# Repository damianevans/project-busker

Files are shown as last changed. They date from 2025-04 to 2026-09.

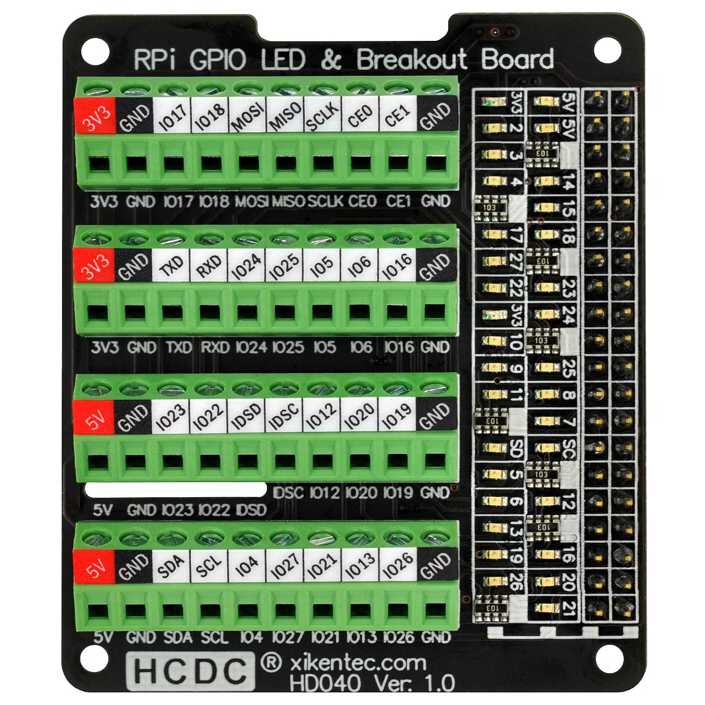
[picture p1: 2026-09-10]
hardware/rpi-gpio-breakout-board.png

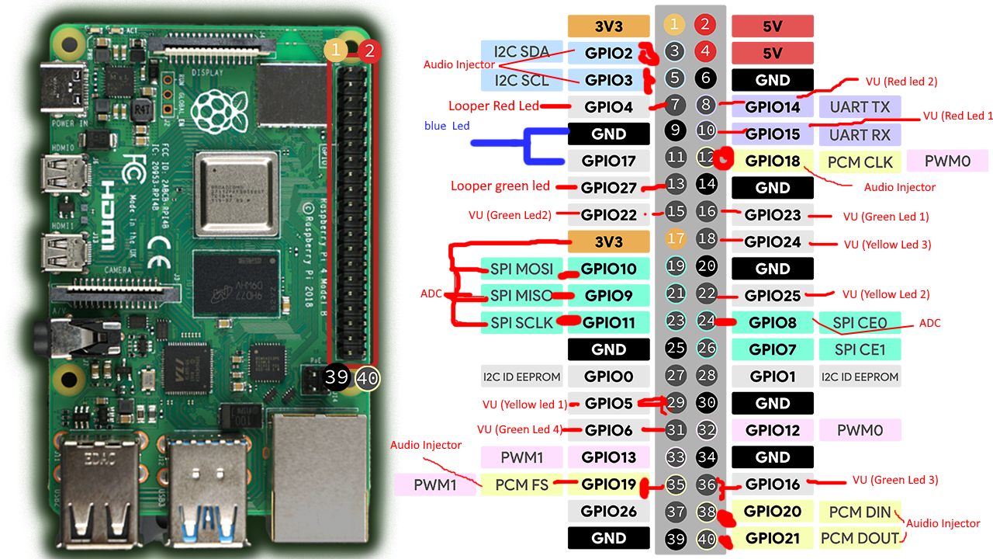
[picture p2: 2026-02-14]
hardware/pi-pins-in-use.png

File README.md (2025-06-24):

# Project Busker

I promised I would build my daughter a busking amp for her Birthday. That was 18 months ago 😫
This project is based on the excellent hackaday article from David Silverman (details below).
The final plan is for a self-contained busking amp with the following features:
- 2 XLR microphone inputs, each with it's own pre-amp and reverb module.
- An electric guitar amp with effects, built using a raspberry pi 4 with an AudioInjector hat
- A hardware mixer
- a power amp

# David Silverman's guitarpedal links
Guitar Pedal for Raspberry pi using Python and PYO library 

Technical documentation being worked on here:

https://docs.google.com/presentation/d/1GgiD2UTEGcz-SC2rGDjdIljaK2Yn0Rs03TDFOu3duUw/edit?usp=sharing

Video demo here:

https://www.youtube.com/watch?v=wl24fLW1fQE

In depth code walkthrough here:

https://www.youtube.com/watch?v=LpFfZ5o4mEs

Looper video here:

https://youtu.be/jMI3nN0OYLE

Hackaday project here:

https://hackaday.io/project/186218-raspberry-pi-guitar-amplifier

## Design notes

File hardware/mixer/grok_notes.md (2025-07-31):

## Notes on the Schematic File
### Components:
- NE5532: Uses the NE5532 symbol from the Amplifier_Operational library in KiCad.
- Capacitors: Generic C symbol from the Device library, set to 10µF (electrolytic, ensure polarity is correct in PCB layout).
- Resistors: Generic R symbol from the Device library, with values specified (10kΩ, 1MΩ, 100Ω, 47Ω, 20kΩ).
- Potentiometers: Uses CPOT from the Device library for 100kΩ faders.
- Connectors:J1: 1/4" TRS jack, approximated as Conn_01x03 (tip, sleeve, ring; sleeve and ring can be grounded for mono).
- J2: 3.5mm TRS jack with switch, approximated as Conn_01x04 (tip, ring, sleeve, switch pin). You may need a custom symbol for a switching 3.5mm jack (see below).

Power: Uses +12V, -12V, and GND symbols from the power library.

### Limitations:
- 3.5mm Jack with Switch: KiCad’s standard library may not have a 3.5mm TRS jack with a switching pin. The schematic uses a Conn_01x04 placeholder. You may need to create a custom symbol in KiCad’s Symbol Editor with pins for tip, ring, sleeve, and a normally closed switch pin that opens when a plug is inserted. Alternatively, use a generic connector and annotate the switching behavior.
- Headphone Output Simplification: The schematic assumes a mono output for simplicity (summing stage feeds both headphone channels). For stereo, duplicate the headphone output stage (U4B, R18, C11) and connect to J2’s ring pin.
- Input Connectors: Channels 1–3 use labels (IN1, IN2, IN3) instead of jacks, as they’re internal connections.

### Connections:
Wires connect components as described in the previous circuit description.
The summing stage (U3A) combines all four channels via 10kΩ resistors (R10–R13).
The output stage splits to line out (via R16) and headphone out (via U4A, R17, C10).
Power connections (±12V, GND) are made to all NE5532 op-amps, with decoupling capacitors (C11, C12: 100nF) near U1/U2.

Coordinates:Components are placed on an A4 sheet with approximate X, Y coordinates (in mils) to avoid overlap.
Channels 1–4 are vertically stacked (Y=2800, 4300, 5800, 7300) for clarity.
Summing stage is at X=5000, output stage at X=7000–8000.

Custom Symbol for 3.5mm Jack (if Needed)If KiCad lacks a 3.5mm TRS jack with a switch, create one:In Symbol Editor: Create a symbol named TRS_3.5mm_Switch.
Add pins:Pin 1: Tip (audio left, input/output).
Pin 2: Ring (audio right, input/output).
Pin 3: Sleeve (ground).
Pin 4: Switch NC (normally closed, connects to line out when unplugged).

Save and use this symbol for J2, connecting Pin 4 to R16 (line out) and Pin 1 to R17 (headphone out).

## Additional Notes

### Mono vs. Stereo: 
The schematic is designed for mono output for simplicity. For stereo, duplicate the headphone output stage (add U4B, R18, C11) and connect to J2’s ring pin.
Power Supply: Ensure ±12V rails are connected to all NE5532 power pins (V+ = pin 8, V- = pin 4). Add more decoupling capacitors (100nF) near U3 and U4 if needed.
Testing: After loading the schematic, simulate in a tool like LTspice (export netlist) to verify gain, frequency response, and headphone drive capability.
Footprint Assignment: Choose appropriate footprints in KiCad’s PCB Editor (e.g., DIP-8_W7.62mm for NE5532, PinHeader_1x3 for J1, PhoneJack_3.5mm for J2).

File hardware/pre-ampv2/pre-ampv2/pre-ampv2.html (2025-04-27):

# C:\Users\admin\Google Drive\KiCad\Busker-amp\guitar-pre-amp\pre-ampv2\pre-ampv2\pre-ampv2.sch

12/03/2025 23:24:18

Eeschema (5.1.10)-1

Component Count:15

Ref | Qnty | Value | Part | Datasheet | Description | Vendor
C1, C3, C5 | 3 | 10u | Device:CP | ~ | Polarized capacitor
C2 | 1 | 0.1u | Device:C | ~ | Unpolarized capacitor
C4 | 1 | 560p | Device:C | ~ | Unpolarized capacitor
J1 | 1 | Conn_01x02_Male | Connector:Conn_01x02_Male | ~ | Generic connector, single row, 01x02, script generated (kicad-library-utils/schlib/autogen/connector/)
J2 | 1 | Out | Connector:Conn_01x02_Male | ~ | Generic connector, single row, 01x02, script generated (kicad-library-utils/schlib/autogen/connector/)
R1, R3 | 2 | 100K | Device:R | ~ | Resistor
R2 | 1 | 1M | Device:R | ~ | Resistor
R4 | 1 | 1K | Device:R | ~ | Resistor
R5 | 1 | 10K | Device:R | ~ | Resistor
R6 | 1 | 220 | Device:R | ~ | Resistor
RV1 | 1 | 100K | Device:R_POT | ~ | Potentiometer
U1 | 1 | NE5532 | Amplifier_Operational:NE5532 | http://www.ti.com/lit/ds/symlink/ne5532.pdf | Dual Low-Noise Operational Amplifiers, DIP-8/SOIC-8

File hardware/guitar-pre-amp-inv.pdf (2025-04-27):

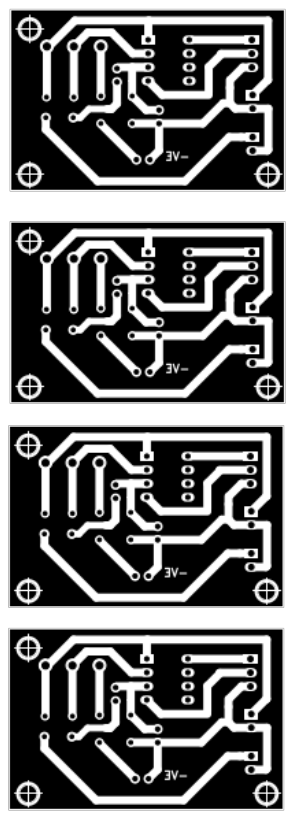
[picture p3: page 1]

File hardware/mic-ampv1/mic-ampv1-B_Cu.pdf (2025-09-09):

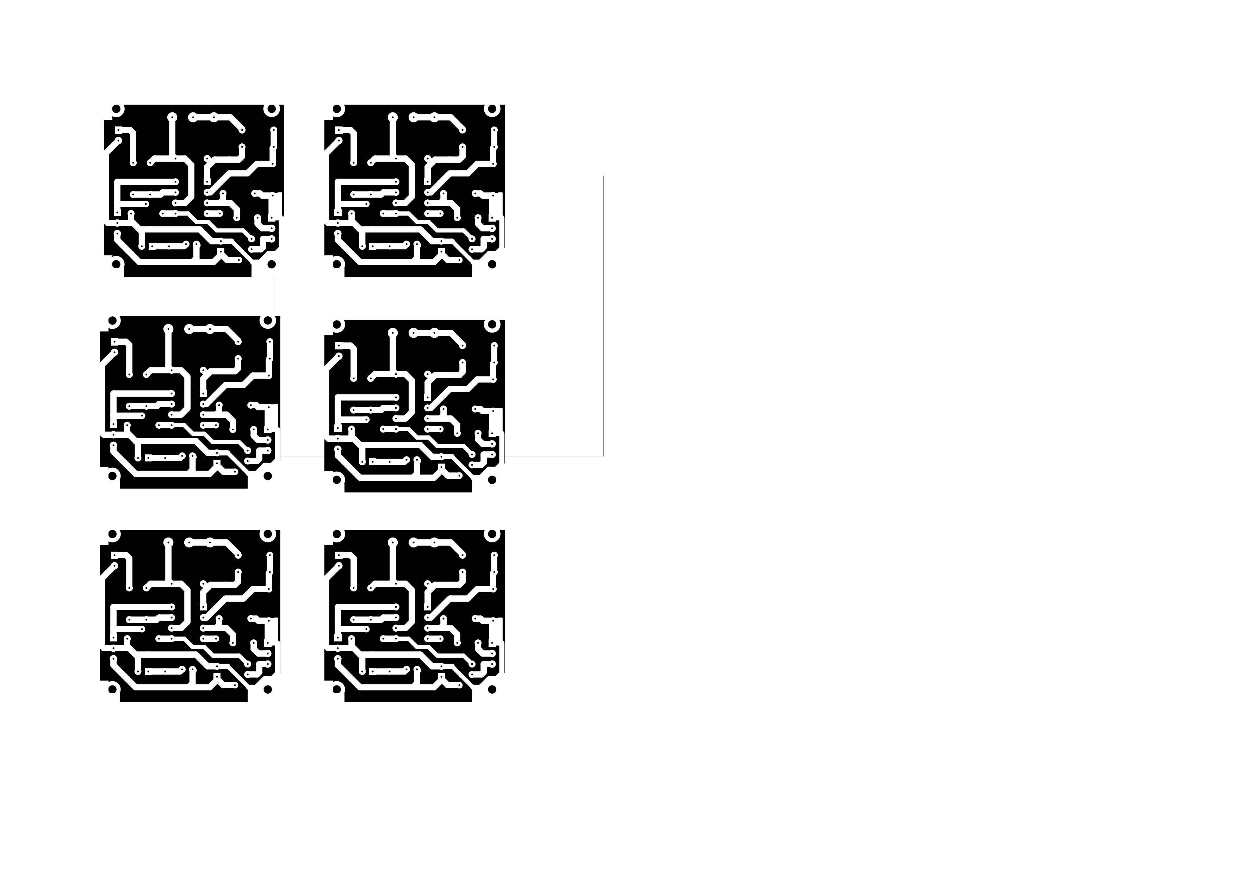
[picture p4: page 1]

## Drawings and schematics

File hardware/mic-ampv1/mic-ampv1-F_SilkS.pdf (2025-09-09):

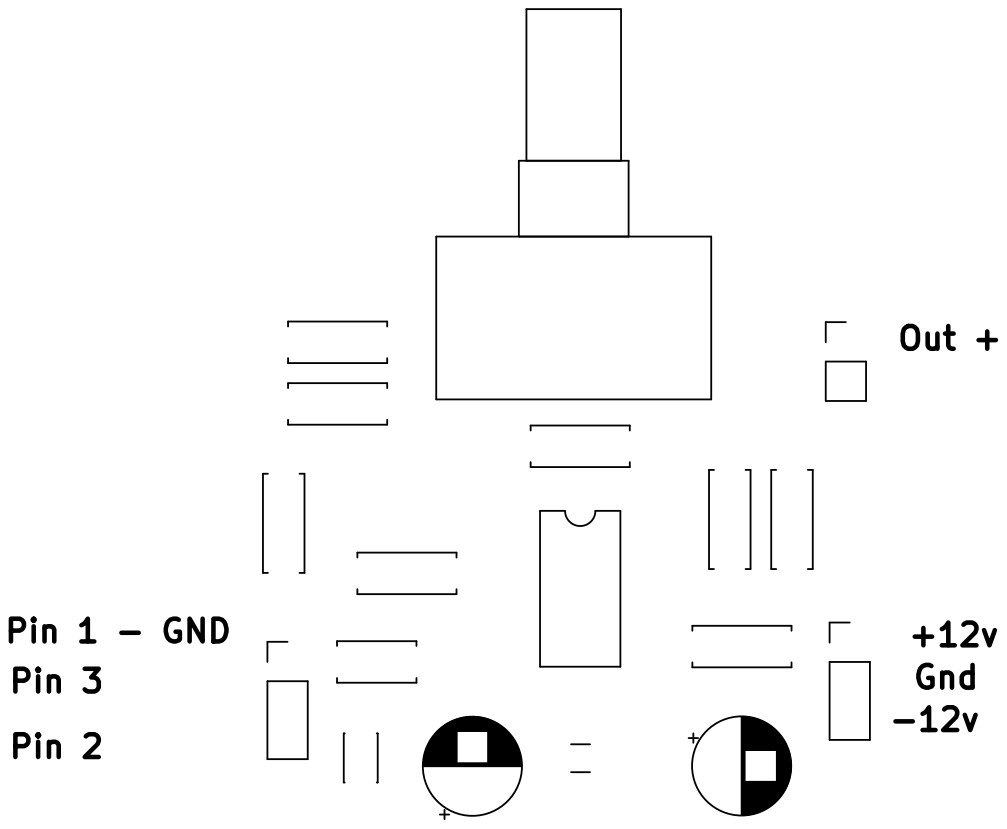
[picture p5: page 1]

+12v Out + Pin 2 Pin 3 Pin 1 - GND

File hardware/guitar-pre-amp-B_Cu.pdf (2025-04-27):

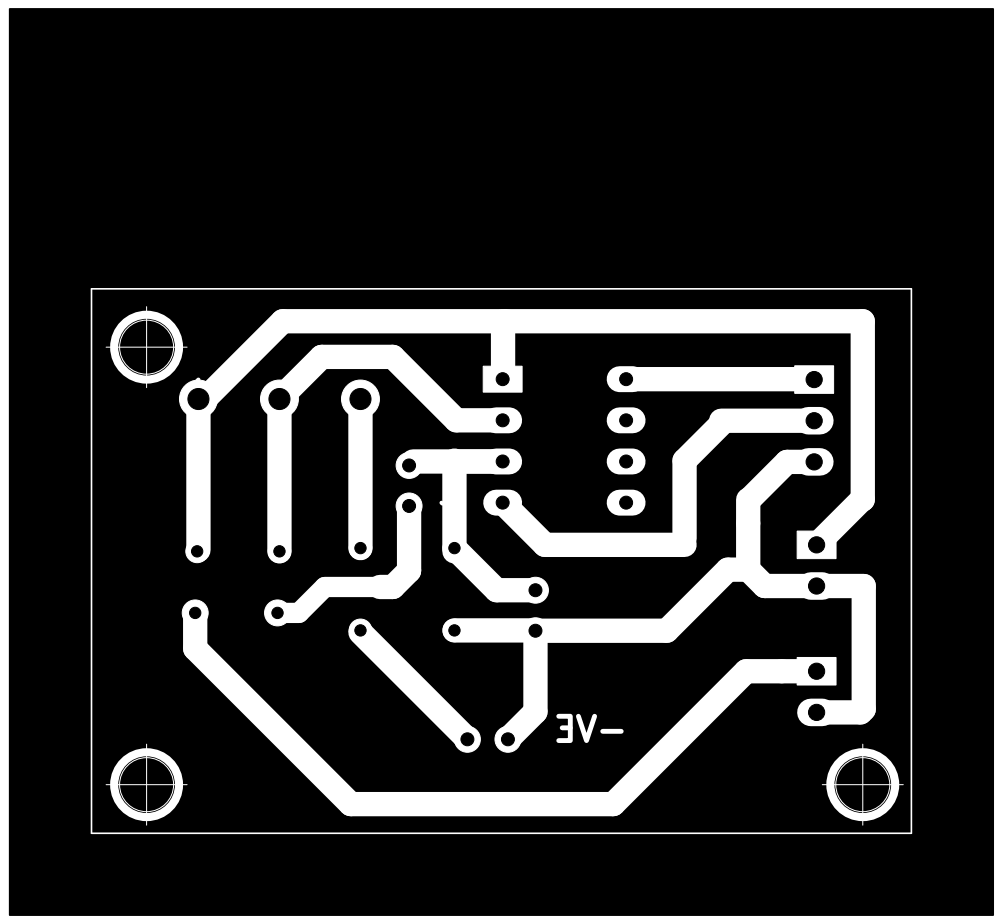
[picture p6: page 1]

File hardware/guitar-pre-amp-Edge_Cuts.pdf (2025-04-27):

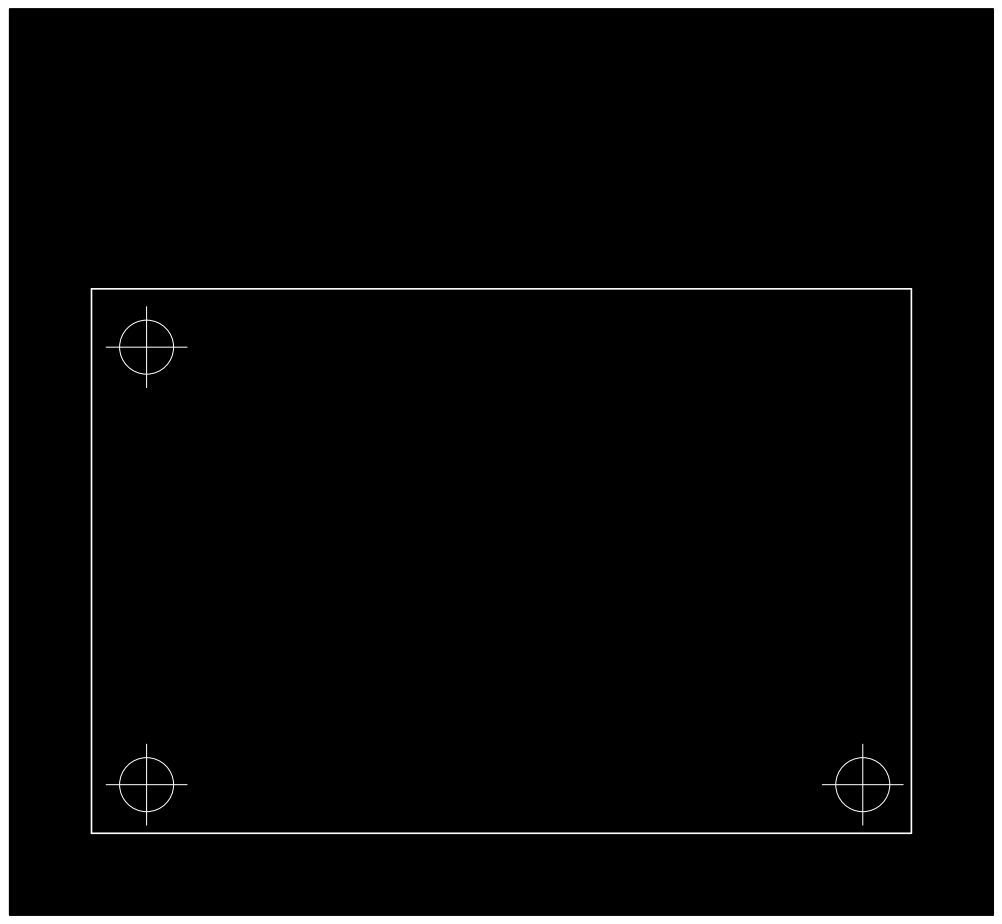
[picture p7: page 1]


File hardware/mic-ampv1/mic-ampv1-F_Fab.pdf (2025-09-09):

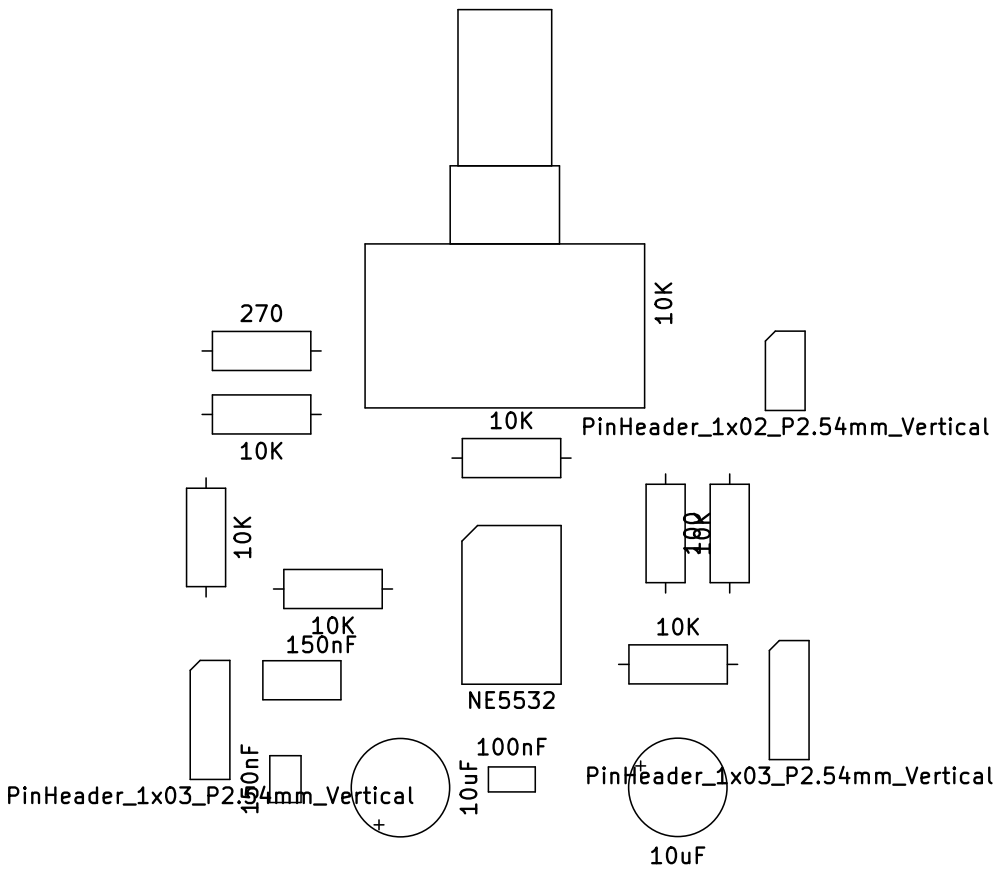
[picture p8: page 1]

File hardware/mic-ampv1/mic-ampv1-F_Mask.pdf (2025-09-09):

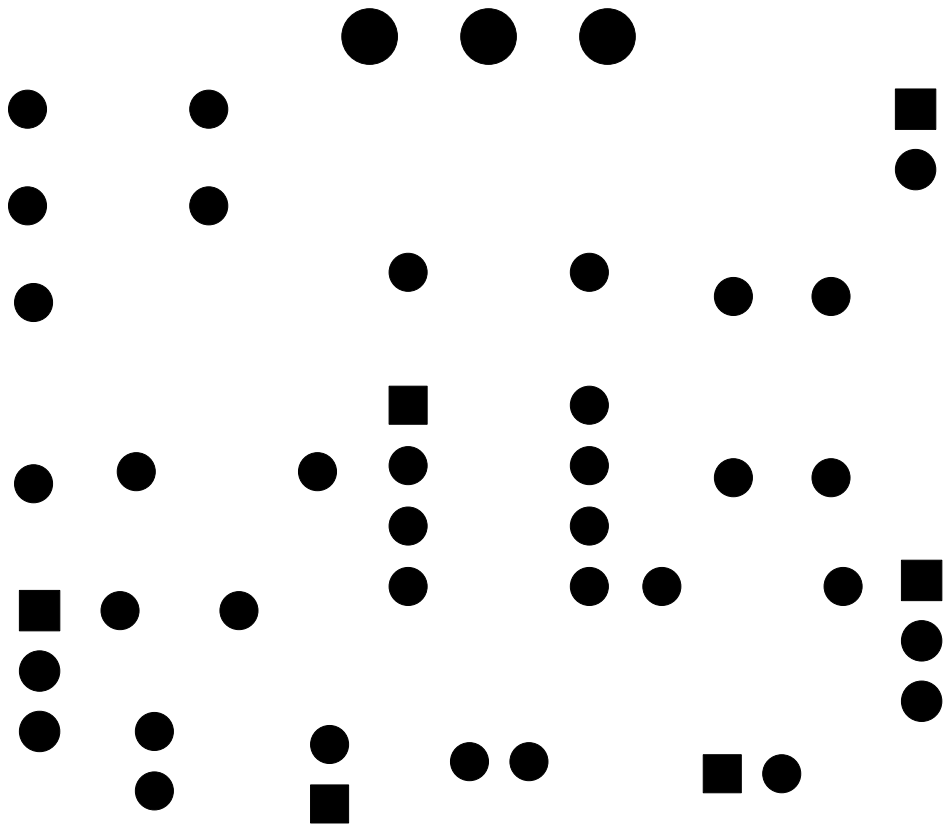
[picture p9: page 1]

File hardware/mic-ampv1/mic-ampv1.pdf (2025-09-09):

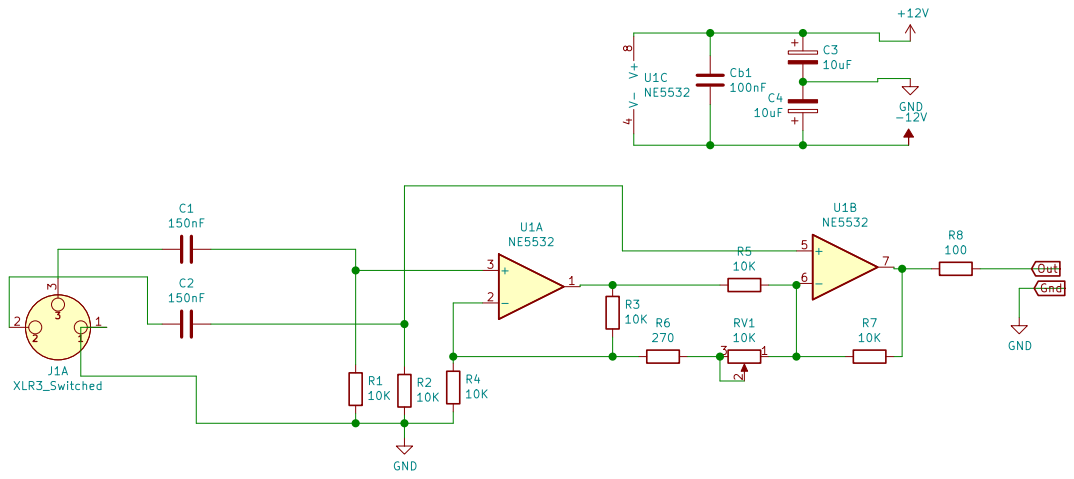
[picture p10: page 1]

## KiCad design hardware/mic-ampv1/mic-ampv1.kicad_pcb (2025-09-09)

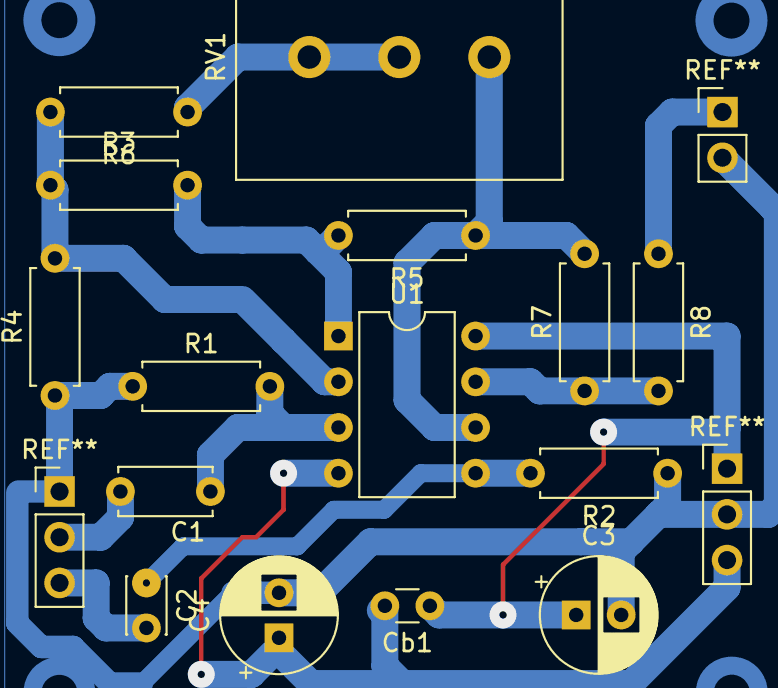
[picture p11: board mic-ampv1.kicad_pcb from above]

Board: 2 copper layers, 15 parts (0 on the bottom side), 10 nets.

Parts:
C1: 150nF; C_Disc_D5.0mm_W2.5mm_P5.00mm
C2: 150nF; C_Disc_D3.0mm_W2.0mm_P2.50mm
C3, C4: 10uF; CP_Radial_D6.3mm_P2.50mm
Cb1: 100nF; C_Disc_D3.0mm_W1.6mm_P2.50mm
R1, R2, R3, R4, R5, R7: 10K; R_Axial_DIN0207_L6.3mm_D2.5mm_P7.62mm_Horizontal
R6: 270; R_Axial_DIN0207_L6.3mm_D2.5mm_P7.62mm_Horizontal
R8: 100; R_Axial_DIN0207_L6.3mm_D2.5mm_P7.62mm_Horizontal
RV1: 10K; Potentiometer_Alps_RK163_Single_Horizontal
U1: NE5532; DIP-8_W7.62mm

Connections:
+12V: C3.1, Cb1.1, U1.8
-12V: C4.1, Cb1.2, U1.4
Gnd: C3.2, C4.2, R1.1, R2.1, R4.1
unnamed: C1.1, R1.2, U1.3
unnamed: C2.1, R2.2, U1.5
unnamed: R3.1, R4.2, R6.2, U1.2
unnamed: R3.2, R5.2, U1.1
unnamed: R5.1, R7.2, RV1.1, U1.6
unnamed: R6.1, RV1.2, RV1.3
unnamed: R7.1, R8.2, U1.7

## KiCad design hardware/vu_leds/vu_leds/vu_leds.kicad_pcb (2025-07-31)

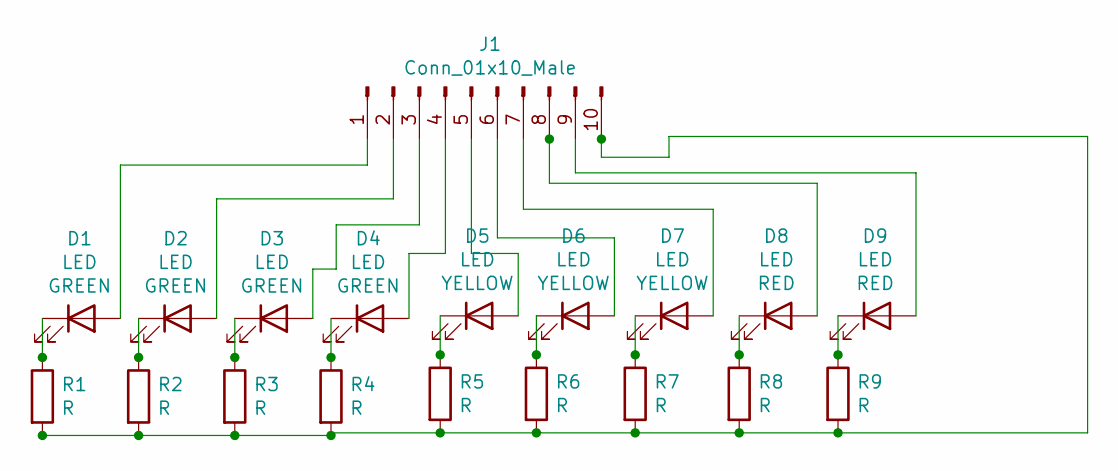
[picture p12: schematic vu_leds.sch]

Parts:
D1, D2, D3, D4, D5, D6, D7, D8, D9: LED; LED_Rectangular_W5.0mm_H2.0mm
J1: Conn_01x10_Male; PinHeader_1x10_P2.54mm_Horizontal
R1, R2, R3, R4, R5, R6, R7, R8, R9: R; R_Axial_DIN0207_L6.3mm_D2.5mm_P7.62mm_Horizontal

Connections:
unnamed: D1.1 (K), R1.1
unnamed: D1.2 (A), J1.1
unnamed: D2.1 (K), R2.1
unnamed: D2.2 (A), J1.2
unnamed: D3.1 (K), R3.1
unnamed: D3.2 (A), J1.3
unnamed: D4.1 (K), R4.1
unnamed: D4.2 (A), J1.4
unnamed: D5.1 (K), R5.1
unnamed: D5.2 (A), J1.5
unnamed: D6.1 (K), R6.1
unnamed: D6.2 (A), J1.6
unnamed: D7.1 (K), R7.1
unnamed: D7.2 (A), J1.7
unnamed: D8.1 (K), R8.1
unnamed: D8.2 (A), J1.8
unnamed: D9.1 (K), R9.1
unnamed: D9.2 (A), J1.9
unnamed: J1.10, R1.2, R2.2, R3.2, R4.2, R5.2, R6.2, R7.2, R8.2, R9.2

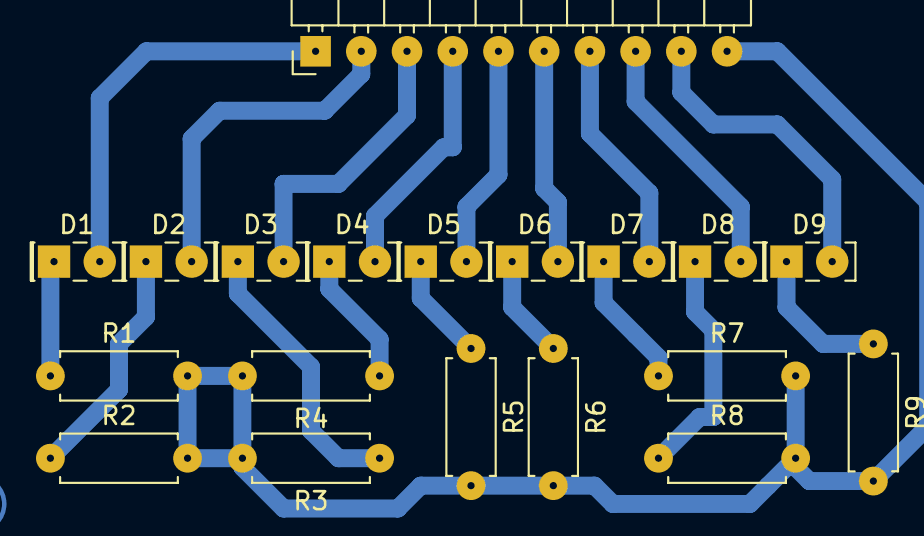
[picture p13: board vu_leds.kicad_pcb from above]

Board: 2 copper layers, 19 parts (0 on the bottom side), 19 nets.

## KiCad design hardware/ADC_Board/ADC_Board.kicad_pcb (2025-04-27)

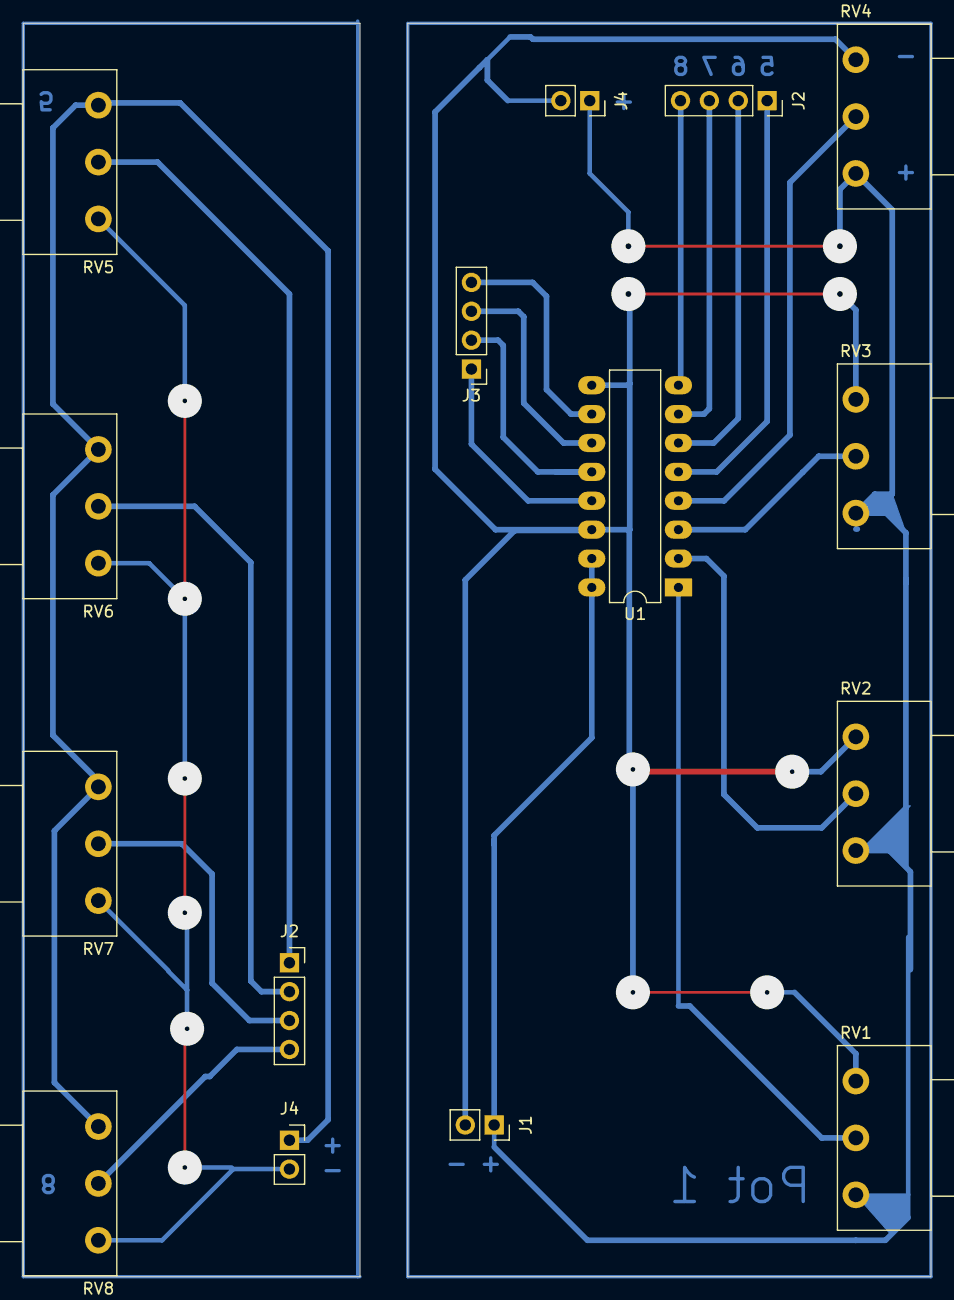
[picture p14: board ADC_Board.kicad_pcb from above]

Board: 2 copper layers, 79.8 x 110.2 mm, 15 parts (0 on the bottom side), 12 nets.

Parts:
J1, J4, J4#2: Conn_01x02_Female; PinSocket_1x02_P2.54mm_Vertical
J2, J2#2: Conn_01x04_Female; PinSocket_1x04_P2.54mm_Vertical
J3: Conn_01x04_Female; PinHeader_1x04_P2.54mm_Vertical
RV1, RV2, RV3, RV4, RV5, RV6, RV7, RV8: R_POT; Potentiometer_Piher_PC-16_Single_Horizontal
U1: MCP3008; DIP-16_W7.62mm_LongPads

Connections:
unnamed: J2#2.1, U1.5
unnamed: J2#2.2, U1.6
unnamed: J2#2.3, U1.7
unnamed: J2#2.4, U1.8
unnamed: J3.1, U1.13
unnamed: J3.2, U1.12
unnamed: J3.3, U1.11
unnamed: J3.4, U1.10
unnamed: RV1.2, U1.1
unnamed: RV2.2, U1.2
unnamed: RV3.2, U1.3
unnamed: RV4.2, U1.4

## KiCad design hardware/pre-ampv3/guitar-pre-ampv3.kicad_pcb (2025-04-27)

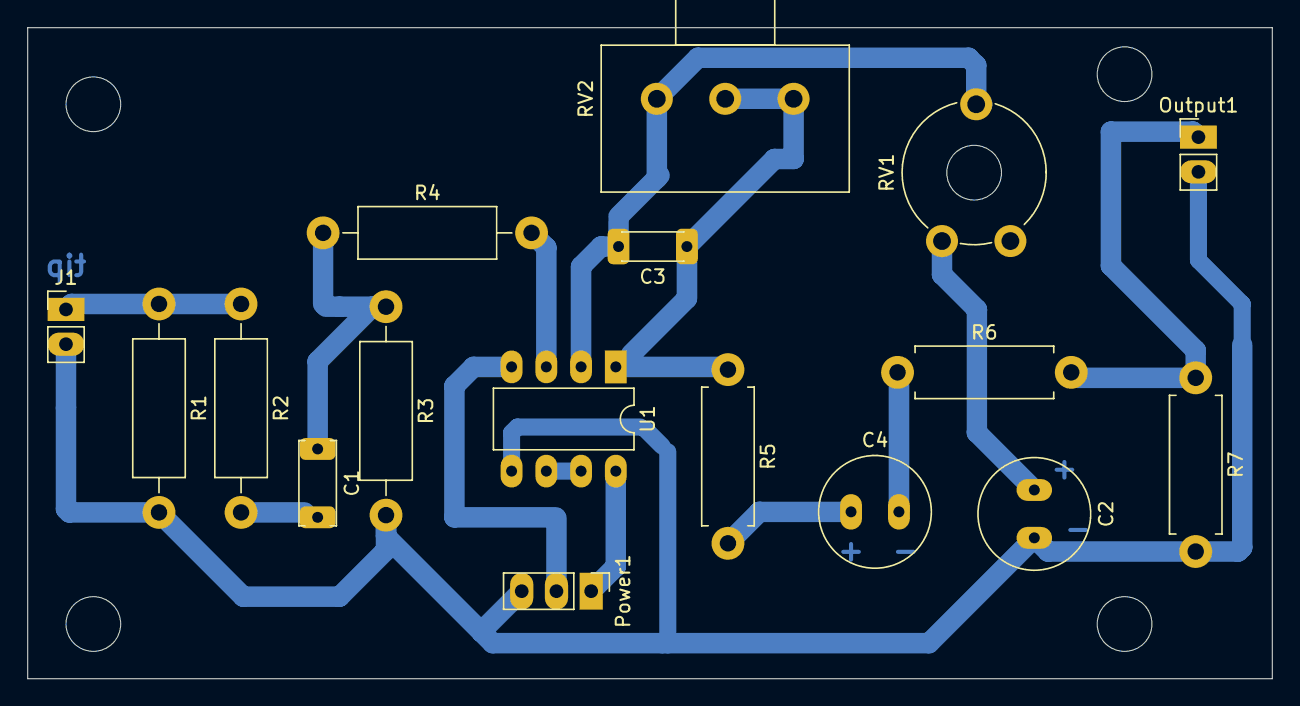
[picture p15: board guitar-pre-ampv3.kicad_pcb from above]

Board: 2 copper layers, 91.0 x 47.6 mm, 17 parts (0 on the bottom side), 12 nets.

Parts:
C1: 100n; C_Disc_D6.0mm_W2.5mm_P5.00mm
C2, C4: 10uF; C_Radial_D8.0mm_H11.5mm_P3.50mm
C3: 100p; C_Disc_D4.3mm_W1.9mm_P5.00mm
J1: Input; PinHeader_1x02_P2.54mm_Vertical
Output1: Conn_01x02_Male; PinHeader_1x02_P2.54mm_Vertical
Power1: pwr; PinHeader_1x03_P2.54mm_Vertical
R1: 470k; R_Axial_DIN0411_L9.9mm_D3.6mm_P15.24mm_Horizontal
R2, R4: 1k; R_Axial_DIN0411_L9.9mm_D3.6mm_P15.24mm_Horizontal
R3: 470K; R_Axial_DIN0411_L9.9mm_D3.6mm_P15.24mm_Horizontal
R5, R6: 1k; R_Axial_DIN0411_L9.9mm_D3.6mm_P12.70mm_Horizontal
R7: 100k; R_Axial_DIN0411_L9.9mm_D3.6mm_P12.70mm_Horizontal
RV1: 10K; Potentiometer_Piher_PT-10-V10_Vertical_Hole
RV2: 50k; Potentiometer_Alps_RK163_Single_Horizontal
U1: NE5532; DIP-8_W7.62mm_LongPads

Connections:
GND: C2.2, J1.2, Output1.2, Power1.3, R1.2, R3.2, R7.2, U1.5
unnamed: C1.1, R3.1, R4.1
unnamed: C1.2, R2.2
unnamed: C2.1, RV1.3
unnamed: C3.1, RV2.1, RV2.2
unnamed: C3.2, RV1.1, RV1.2, RV2.3, U1.2
unnamed: C4.1, R5.2
unnamed: C4.2, R6.1
unnamed: J1.1, R1.1, R2.1
unnamed: Output1.1, R6.2, R7.1
unnamed: R4.2, U1.3
unnamed: R5.1, U1.1

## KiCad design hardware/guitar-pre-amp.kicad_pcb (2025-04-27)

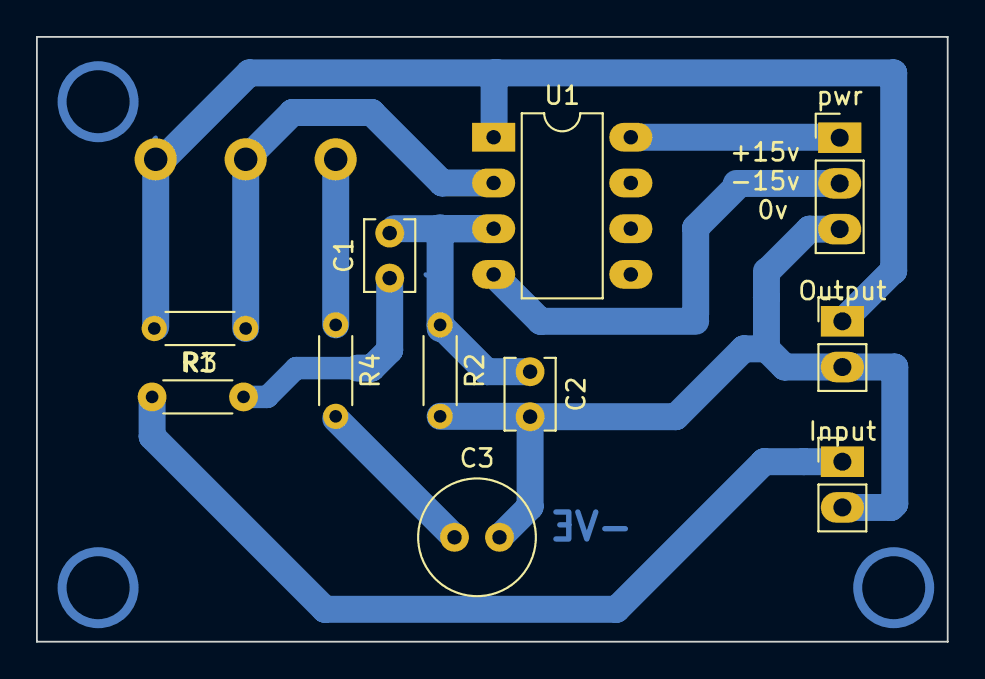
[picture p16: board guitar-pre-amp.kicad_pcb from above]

Board: 2 copper layers, 50.6 x 33.6 mm, 12 parts (1 on the bottom side), 8 nets.

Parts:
C1: 100nF; C_Disc_D3.8mm_W2.6mm_P2.50mm
C2: 100pF; C_Disc_D3.8mm_W2.6mm_P2.50mm
C3: 100uF; C_Radial_D6.3mm_H5.0mm_P2.50mm
Input: PinHeader_1x02_P2.54mm_Vertical
Output: .; PinHeader_1x02_P2.54mm_Vertical
R1: 100; R_Axial_DIN0204_L3.6mm_D1.6mm_P5.08mm_Horizontal
R2: 1M; R_Axial_DIN0204_L3.6mm_D1.6mm_P5.08mm_Horizontal
R3: 100K; R_Axial_DIN0204_L3.6mm_D1.6mm_P5.08mm_Horizontal
R4: 330; R_Axial_DIN0204_L3.6mm_D1.6mm_P5.08mm_Horizontal
RV1: 100K; Potentiometer_Alps_RK163_Single_Horizontal
U1: NE5532; DIP-8_W7.62mm_LongPads
pwr: .; PinHeader_1x03_P2.54mm_Vertical

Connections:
GND: C2.2, C3.2, Input.2, Output.2, R2.2, pwr.3
unnamed: C1.1, R1.2
unnamed: C1.2, C2.1, R2.1, U1.3
unnamed: C3.1, R4.2
unnamed: Input.1, R1.1
unnamed: Output.1, R3.2, RV1.1, U1.1
unnamed: R3.1, RV1.2, U1.2
unnamed: R4.1, RV1.3

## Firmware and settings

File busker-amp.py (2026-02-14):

import pyo64
import time
import os
import shutil
from gpiozero import MCP3008, LEDBarGraph, LED
import threading
from modules.bt_footswitch_recv import ESP32BLEClient
import asyncio


s = pyo64.Server()
s.setInOutDevice(1)
s.boot()
s.start()

audio    = pyo64.Input()
dry      = pyo64.Input()

cdir        = os.path.dirname(os.path.abspath(__file__))
silence     = cdir+'/silent.wav'
loop_file   = cdir+'/pedalloop.wav'
print(f"Using silence file: {silence}")
print(f"Using loop file: {loop_file}")
shutil.copy(silence,loop_file)
loop_vol    = 0.9

# Initialize loop player once - don't recreate it
loop_play = pyo64.SfPlayer(loop_file, loop=True, mul=loop_vol)
loop_rec    = None
looperState = oldLooperState = "IDLE"

follow   = pyo64.Follower(audio)
wahfq    = pyo64.Scale(follow, outmin=300, outmax=20000)
chorus   = pyo64.Chorus(audio, feedback=0.25, bal=1)
#delay    = pyo64.SmoothDelay(audio, feedback=0.15)
reverb   = pyo64.Freeverb(chorus)
distort  = pyo64.Disto(reverb)
filter   = pyo64.MultiBand(distort, num=3, mul=[1,1,1])
wet      = pyo64.Mix([filter])
wah      = pyo64.ButBP(wet, freq=wahfq, q=30)

mix = pyo64.Mix([dry, wet, wah]).out()       # Main effects mix

amplitude = None
leds_on = True
#eq = {'bass': 1., 'mid': 1., 'treb': 1.}
#fx = {'wet': 1., 'dry': 1., 'delay': 1., 'reverb':1., 'distort': 1., 'wah': 1.}
fx = {'bass': 0, 'mid': 0, 'treb': 0,'wet': 0, 'dry': 0, 'chorus': 0, 'reverb':0, 'distort': 0, 'wah': 0}
data_lock = threading.Lock()
max_RMS = 0
VU_factor = 1
led_gr1 = "BOARD16" # GPIO23
led_gr2 = "BOARD15" # GPIO22
led_gr3 = "BOARD36" # GPIO 16
led_gr4 = "BOARD31" #GPIO 6

led_yel1 = "BOARD29" #GPIO 5
led_yel2 = "BOARD22" #GPIO 25
led_yel3 = "BOARD18" #GPIO 24

led_red1 = "BOARD10" #GPIO15 / RX
led_red2 = "BOARD8" #GPIO14 / TX

vu_leds = LEDBarGraph(led_gr1, led_gr2, led_gr3, led_gr4,
                      led_yel1, led_yel2, led_yel3,
                      led_red1, led_red2)
vu_leds.off()
vu_leds.value = 0
bt_led = LED("BOARD11") # GPIO 17
looper_led_red = LED("BOARD7") #GPIO4
looper_led_green = LED("BOARD13") #GPIO27


def RMS_meter_callback(*args):
    global max_RMS, VU_factor, meter
    # set VU max to highest value, but back off highest value over time
    if args[0] > max_RMS:
        max_RMS = args[0]
        VU_factor = 9/max_RMS # number of VU bars is 20
    elif max_RMS > 0.05:  
        max_RMS -= 0.005
    if leds_on:
        vu_leds.value = min([1,args[0]*VU_factor/9])

def inputLoop():
    global amplitude, loop_rec, loop_play, loop_file, silence
    amplitude = pyo64.RMS(mix, function=RMS_meter_callback)
    def getDataMessage(address, *args):
        global amplitude, loop_rec, loop_play, loop_file, silence
        if address == "/data/eq":
            #with data_lock:
            fx['bass'], fx['mid'], fx['treb'], fx['wet'], fx['dry'], fx['chorus'], fx['reverb'], fx['distort'], fx['wah'] = args
            filter.mul = [fx['bass']*100, fx['mid']*100, fx['treb']*100]
            dry.mul         = 1 - fx['dry']
            wet.mul         =     fx['wet'] 
            chorus.depth    =     fx['chorus']
        #    delay.delay     =     fx['delay']            
            reverb.size     =     fx['reverb']
            distort.drive   =     fx['distort']
            wah.mul         =     fx['wah']
        elif address == "/data/looperstate":
            localLooperState = args[0].upper()  
            print(f"Looper state changed to: {localLooperState}")
            if localLooperState == "IDLE":
                # reset red/green leds
                looper_led_red.off()
                looper_led_green.off()
                # Stop everything
                if loop_play.isPlaying():
                    loop_play.stop()    
                if loop_rec is not None:
                    loop_rec.stop()
                    loop_rec = None
                    
            elif localLooperState == "RECORDING":
                print("Starting recording...")
                looper_led_red.on()
                looper_led_green.off()
                # Stop playback and start recording
                if loop_play.isPlaying():
                    loop_play.stop()
                if loop_rec is not None:
                    loop_rec.stop()
                
                # Clear the loop file and start fresh recording
                shutil.copy(silence, loop_file)
                
                # Create new Record object and start recording
                loop_rec = pyo64.Record(mix, filename=loop_file, fileformat=0, sampletype=1)
                print("Recording active")
                
            elif localLooperState == "PLAYBACK":
                looper_led_red.off()
                looper_led_green.on()
                # Stop recording if active
                if loop_rec is not None:
                    print("Stopping recording...")
                    loop_rec.stop()
                    loop_rec = None
                    # FIX 2: Give more time for the file to be written and flushed
                    time.sleep(0.2)  # Increased from 0.1 to 0.2
                
                # Stop current player and create new one with updated file
                if loop_play.isPlaying():
                    loop_play.stop()
       
                # Recreate the player with the new recorded content
                print("Starting playback...")
                loop_play = pyo64.SfPlayer(loop_file, loop=True, mul=loop_vol,).out()
            elif localLooperState == "STOPPED":
                #red led off, green blink
                looper_led_red.off()
                looper_led_green.blink()
                # Stop everything but keep recorded content
                if loop_play.isPlaying():
                    loop_play.stop()    

                if loop_rec is not None:
                    loop_rec.stop()
                    loop_rec = None
                print("Playback stopped")
                
            elif localLooperState == "ERASE":
                # Stop everything and clear the loop
                if loop_play.isPlaying():
                    loop_play.stop()
                if loop_rec is not None:
                    loop_rec.stop()
                    loop_rec = None
                
                # Clear the loop file
                shutil.copy(silence, loop_file)
                
                # Recreate player with empty file
                loop_play = pyo64.SfPlayer(loop_file, loop=True, mul=loop_vol)
                loop_play.stop()
                print("Loop erased")

    recv = pyo64.OscDataReceive(port=9900, address="/data/*", function=getDataMessage)
    
    while(True):
        time.sleep(0.05)  # Sleep to avoid busy waiting
            

def controlLoop():
    numlines = 8

    
    pots = [MCP3008(channel=n) for n in range(numlines)]  
    vals = [0] * numlines
    sender = pyo64.OscDataSend(types="fffffffff", port = 9900, address = "/data/eq", host = "localhost")

    while True:
        with data_lock:
            new_vals = [1- int(pots[n].value*100)/100 for n in range(numlines)]
            for i, nv in enumerate(new_vals):
                if abs(vals[i]-nv) > 0.1:
                    vals[i] = nv

        wet = vals[0]
        bass = vals[1]*2
        mid = vals[2]*2
        treb = vals[3]*2
        dry = 1 - wet
        chorus = vals[4]
        reverb = vals[5]
        distort = vals[6]**0.05
        wah = vals[7]*30

 
        sender.send([bass, mid, treb, wet, dry, chorus, reverb, distort, wah])
        time.sleep(0.05)

async def pedalLoop():
    global looperState
    global oldLooperState
    bt_led.blink(on_time=0.5, off_time=0.75)  # Blink to indicate start
    looper_led_red.off()
    looper_led_green.off()
    looperState = oldLooperState = "IDLE"
    ble_client = ESP32BLEClient("ESP32")
    #print("Connecting to ESP32...")
    loopSender = pyo64.OscDataSend(types="s", port = 9900, address = "/data/looperstate", host = "localhost")
    try:
        # Connect to ESP32
        if not await ble_client.connect():
            print("Failed to connect to ESP32. Try re-starting the device.")
            return
        
        # Main loop
        while ble_client.connected:
            try:
                await asyncio.sleep(0.5)
                bt_led.on()  # Turn on the LED to indicate connection
                looperState = ble_client.get_latest_looperstate()
                if looperState != oldLooperState:
                    # flash the LED to indicate state change
                    bt_led.blink(on_time=0.1, off_time=0.1, n=2)
                    await ble_client.send_message("RECV:" + looperState)
                    oldLooperState = looperState
                    loopSender.send([looperState])  # Send the state to the server
                # Optional: Send a test message every 30 seconds
                # await ble_client.send_message("Hello from Pi!")
                
            except KeyboardInterrupt:
                print("\nShutting down...")
                break
                
    except Exception as e:
        print(f"Application error: {e}")
        
    finally:
        await ble_client.disconnect()
        bt_led.off()

async def run_pedal_loop():
   global pedal_loop_task
   pedal_loop_task = asyncio.create_task(pedalLoop())  # Start pedalLoop initially
   while True:
       await asyncio.sleep(0.07)  # Keep the event loop running


if __name__ == "__main__":
    # Create threads
    thread1 = threading.Thread(target=inputLoop)
    thread2 = threading.Thread(target=controlLoop)
    # thread3 = threading.Thread(
    #     target=display_loop, 
    #     args=(fx, looperState, oldLooperState, data_lock), 
    #     daemon=True
    # )

    thread1.start()
    thread2.start()
    # thread3.start()
    try:
        asyncio.run(run_pedal_loop())
        # Join the threads to the main thread to keep them running
    except KeyboardInterrupt:
        print("Main thread stopped")          
    finally:
        pedal_loop_task.cancel()
        thread1.join()
        thread2.join()

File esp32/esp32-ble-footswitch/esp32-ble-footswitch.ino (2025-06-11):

// ========================================
// File: esp32-ble-temperature.ino (main Arduino file)
// ========================================
#include "BLEManager.h"
#include "BLECallbacks.h"
#include "FootSwitch.h"

FootSwitch footSwitch;
const int blueLEDPin = 18;      // Blue LED
  
void setup() {
  Serial.begin(115200);
  
  // Initialize BLE Manager
  BLEManager::init("ESP32");
  footSwitch.init();
}

void sendErase() {
  if(!BLEManager::isConnected()) {
    BLEManager::handleConnection();
  }

  if (BLEManager::isConnected() && footSwitch.getEraseRecordingState()) {
      BLEManager::sendData(String("ERASE"));
      footSwitch.setEraseRecordingState(true);

      // Wait for "RECV:ERASE" response
      unsigned long startTime = millis();
      eraseAckReceived = false; // Reset the flag
      while (!eraseAckReceived) {
          BLEManager::handleConnection(); // Keep handling BLE events
          if (millis() - startTime > 5000) { // Timeout after 5 seconds
              Serial.println("Timeout waiting for RECV:ERASE");
              break;
          }
          delay(10); // Small delay to avoid busy-waiting
      }

      if (eraseAckReceived) {
          Serial.println("RECV:ERASE response received!");
      }
  }
}

void loop() {
  footSwitch.update();
  // Handle BLE connection state
  BLEManager::handleConnection();
  
  if (BLEManager::isConnected()) {
    digitalWrite(blueLEDPin, HIGH); // Turn on blue LED when connected
  } else {
    digitalWrite(blueLEDPin, LOW); // Turn off blue LED when not connected
  }
  
  if(footSwitch.getEraseRecordingState()) {
    sendErase();
    footSwitch.setEraseRecordingState(false); // Reset the erase state after sending
  }

  if(footSwitch.hasStateChanged()) {
    Serial.println("Sending '" +  footSwitch.getStateName(footSwitch.getCurrentState()) + "' via bluetooth");
    // Send foot switch sate data if device is connected
    if (BLEManager::isConnected()) {
      String tempStr = footSwitch.getStateName(footSwitch.getCurrentState());
      BLEManager::sendData(tempStr);
    }    
  }
  delay(100);
}

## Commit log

2025-04-27 effects not working yet
    [busker-amp.py]
2025-04-27 added Circuit schematics and PCB layouts
    [ADC_Board.kicad_pcb, ADC_Board.sch, guitar-pre-amp.kicad_pcb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]
2025-04-27 fix data url for OSC
    [busker-amp.py]
2025-05-24 merging buttons & bluetooth code
2025-05-28 complete buttons and BLE bluetooth send
2025-05-30 fix async send call
    [busker-amp.py]
2025-05-30 update connection error message
    [busker-amp.py]
2025-05-30 moved files for Arduino ide compatibility
2025-05-31 fix led pin conflict
    [busker-amp.py]
2025-05-31 use external led on ESP32
2025-05-31 blue led status
2025-05-31 led flash
2025-05-31 esp32 tweak startup sequence
2025-06-04 change threading. fix record & play options
    [busker-amp.py]
2025-06-04 remove all async thread and record
2025-06-08 won't start up anymore :-(
    [busker-amp.py]
2025-06-08 fix rms meter callback
    [busker-amp.py]
2025-06-08 revert back to orig looper
    [busker-amp.py]
2025-06-11 recoring works, trying to fix play
    [busker-amp.py]
2025-06-15 VU Leds PCB Layout added
    [vu_leds.kicad_pcb, vu_leds.sch]
2025-06-17 pdf of pcb layout
    [vu_leds.kicad_pcb]
2025-06-17 made pcb smaller
    [vu_leds.kicad_pcb]
2025-07-12 updated pins diagram AI generated mixer sch (not very good)
    [mixer.kicad_pcb, vu_leds.kicad_pcb]
2025-07-12 changed vu leds
2025-07-12 changed VU Graph status. Fix NumLeds
    [busker-amp.py]
2025-08-31 complete pcb for mic
    [mic-ampv1.backup.kicad_pcb, mic-ampv1.kicad_pcb, mic-ampv1.sch]
2026-02-14 Added GPIO pin numbers to led designations. Assigned pins for looper leds
2026-02-14 pulled leds png file into main
2026-02-14 reset looper leds state
    [busker-amp.py]
2026-02-14 Added looper led states
2026-09-10 Add files via upload
    nice big picture of the RPI breakout board
